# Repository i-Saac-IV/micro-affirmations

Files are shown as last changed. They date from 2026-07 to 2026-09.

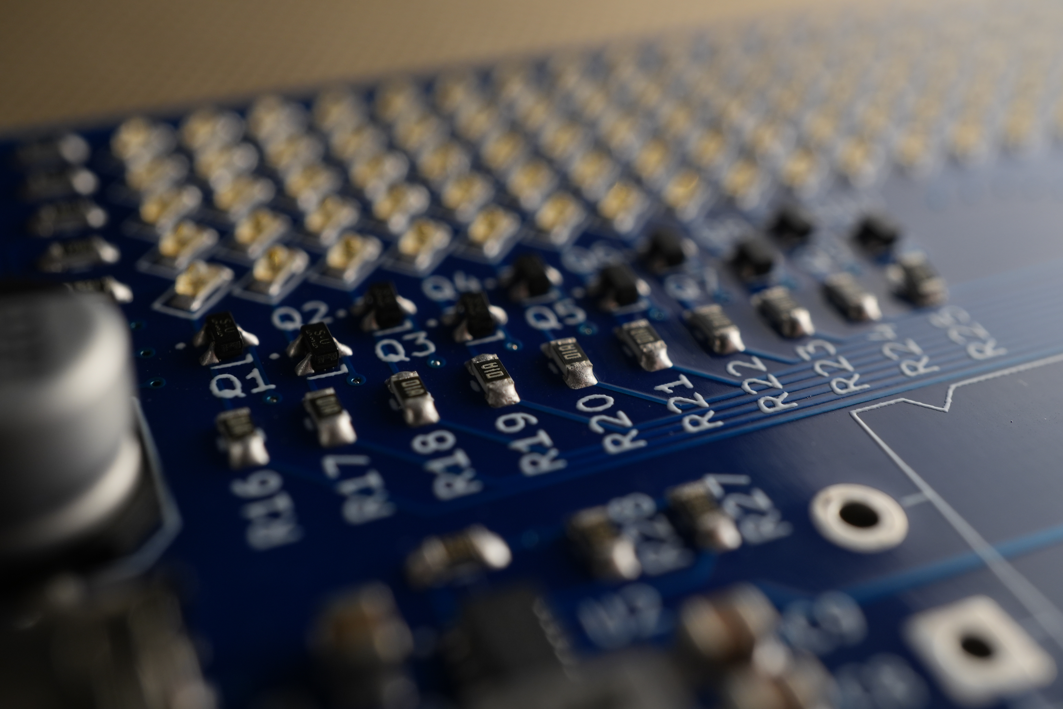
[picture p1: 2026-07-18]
media/DSC01119.JPG

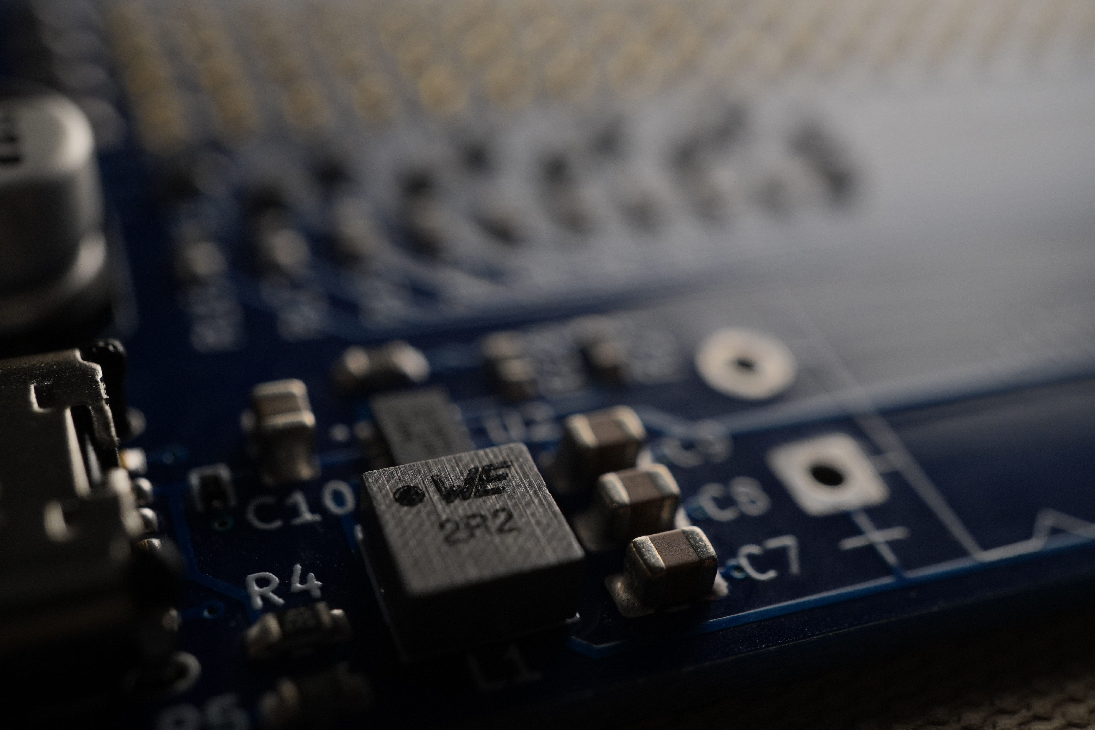
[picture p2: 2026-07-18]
media/DSC01122.JPG

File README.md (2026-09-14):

# µAffirmations
A microcontroller-based affection-giving MACHINE!

> [!IMPORTANT]
> This project is currently a work-in-progress, there __will__ be things that don't work, please bear with me will I work out the kinks!

# Table of Contents
- [Usage Guide](#usage-guide)
  - [Hardware](#hardware)
  - [Firmware](#firmware)
- [Photos](#photos)
- [Project Updates](#project-updates)
- [Copyright and Licensing](#copyright-and-licensing)
- [Contact](#contact)

# Usage Guide
## Hardware
The PCB files can be found [here](/hw/pcb/micro-affirmations.zip), be sure of order a solder stencil too(ideally with a stencil unless you love hand-soldering 200+ SMD connections). The [BOM](/hw/pcb/bom/ibom.html) will provide you with a list of parts required and their placements. Due to the limited size on the PCB, many of the reference designators have been removed to save space. Because of this, you will likely need to have KiCAD or the iBOM running as you are placing components. Or you can guess I suppose...

## Firmware
You will need access to an ST-Link programming device and have [stm32-for-vscode](https://open-vsx.org/extension/bmd/stm32-for-vscode) extension installed. Once you're ready, upload the code by:
- Cloning the repository
- Open in VS code
- Connect the ST-Link programmer to your computer
- Connect the µAffirmations' programming port to the ST-Link programmer
- Ensure the µAffirmations board is powered
- Open the STM32 for VS Code extention
- Click __Flash STM32__

### Message customisation
This device allows the user to create their own custom messages to be displayed on the LED matrix, to provide your messages, modify the following code found in [this](/Core/Src/messages.c) file.

For axample:
```c
__weak const char *messages[] = {
    "This is the first custom message!",
    "Below is a list of supported characters...",
    "!\"#$%&'()*+,-./0123456789:;<=>?@ABCDEFGHIJKLMNOPQRSTUVWXYZ[\\]^_`abcdefghijklmnopqrstuvwxyz{|}~"
};
```

# Photos
<table align="center">
  <tr>
    <td align="center">
      <br>
      <b>Programming port broken in RevB of the PCB</b>
    </td>
  </tr>
</table>

# Project Updates
## Hardware [RevD](https://github.com/i-Saac-IV/micro-affirmations/tree/v0.9.3)
After considerable development to the code, I found out that I had not connected the supercapacitor voltage sensing circuit to a ADC capable pin, this has been corrected. I also found that if the input voltage of the charging IC is greater than the output voltage = 100mV the bucking function of the IC is bypassed (meaning if the input is 5V the output is also 5V, bad for the STM chip), this has been fixed with the linear regulator.

## Hardware [RevC](https://github.com/i-Saac-IV/micro-affirmations/tree/v0.9.2)
After futher testing the following fixes to the hardware design have been made:
- The programming port has been connected to the correct pins on the mircocontroller
- The layout of the components has been adjusted for easier access to the push button
- The supercapacitor management circuit has been de-routed as per the spec sheet
- I added a QR to the PCB, because I could...

## Hardware [RevB](https://github.com/i-Saac-IV/micro-affirmations/tree/v0.9.1)
After hardware tesing the following fixes have been made to the hardware design:
- Supercapacitor charging circuit, now uses a dedecated IC
- LED matrix layout, the LED spacing has been decreased
- LED brightness was assessed and appropriate resistor have been selected
- The overall PCB dimentions have shrunk to 70x40mm
<table align="center">
  <tr>
    <td align="center">
      <br>
      <b>RevB PCB</b>
    </td>
  </tr>
</table>

## Hardware [RevA](https://github.com/i-Saac-IV/micro-affirmations/tree/v0.9.0)
Initial hardware design.

# Copyright and Licensing
See [licence](LICENSE) for in depth info.
<!--
This project uses the following third-party libraries:

- Lib ( License)

Copyright and license terms belong to their respective authors.

Contact me if anything here is incorrect.
-->

# Contact
If you'd like to get in touch, feel free to reach out!
<p>
  <a href="https://github.com/i-Saac-IV">
    
  </a>
  <a href="https://www.linkedin.com/in/isaac-pawley/">
    
  </a>
  <a href="https://www.instagram.com/i.saac.0100/">
    
  </a>
</p>

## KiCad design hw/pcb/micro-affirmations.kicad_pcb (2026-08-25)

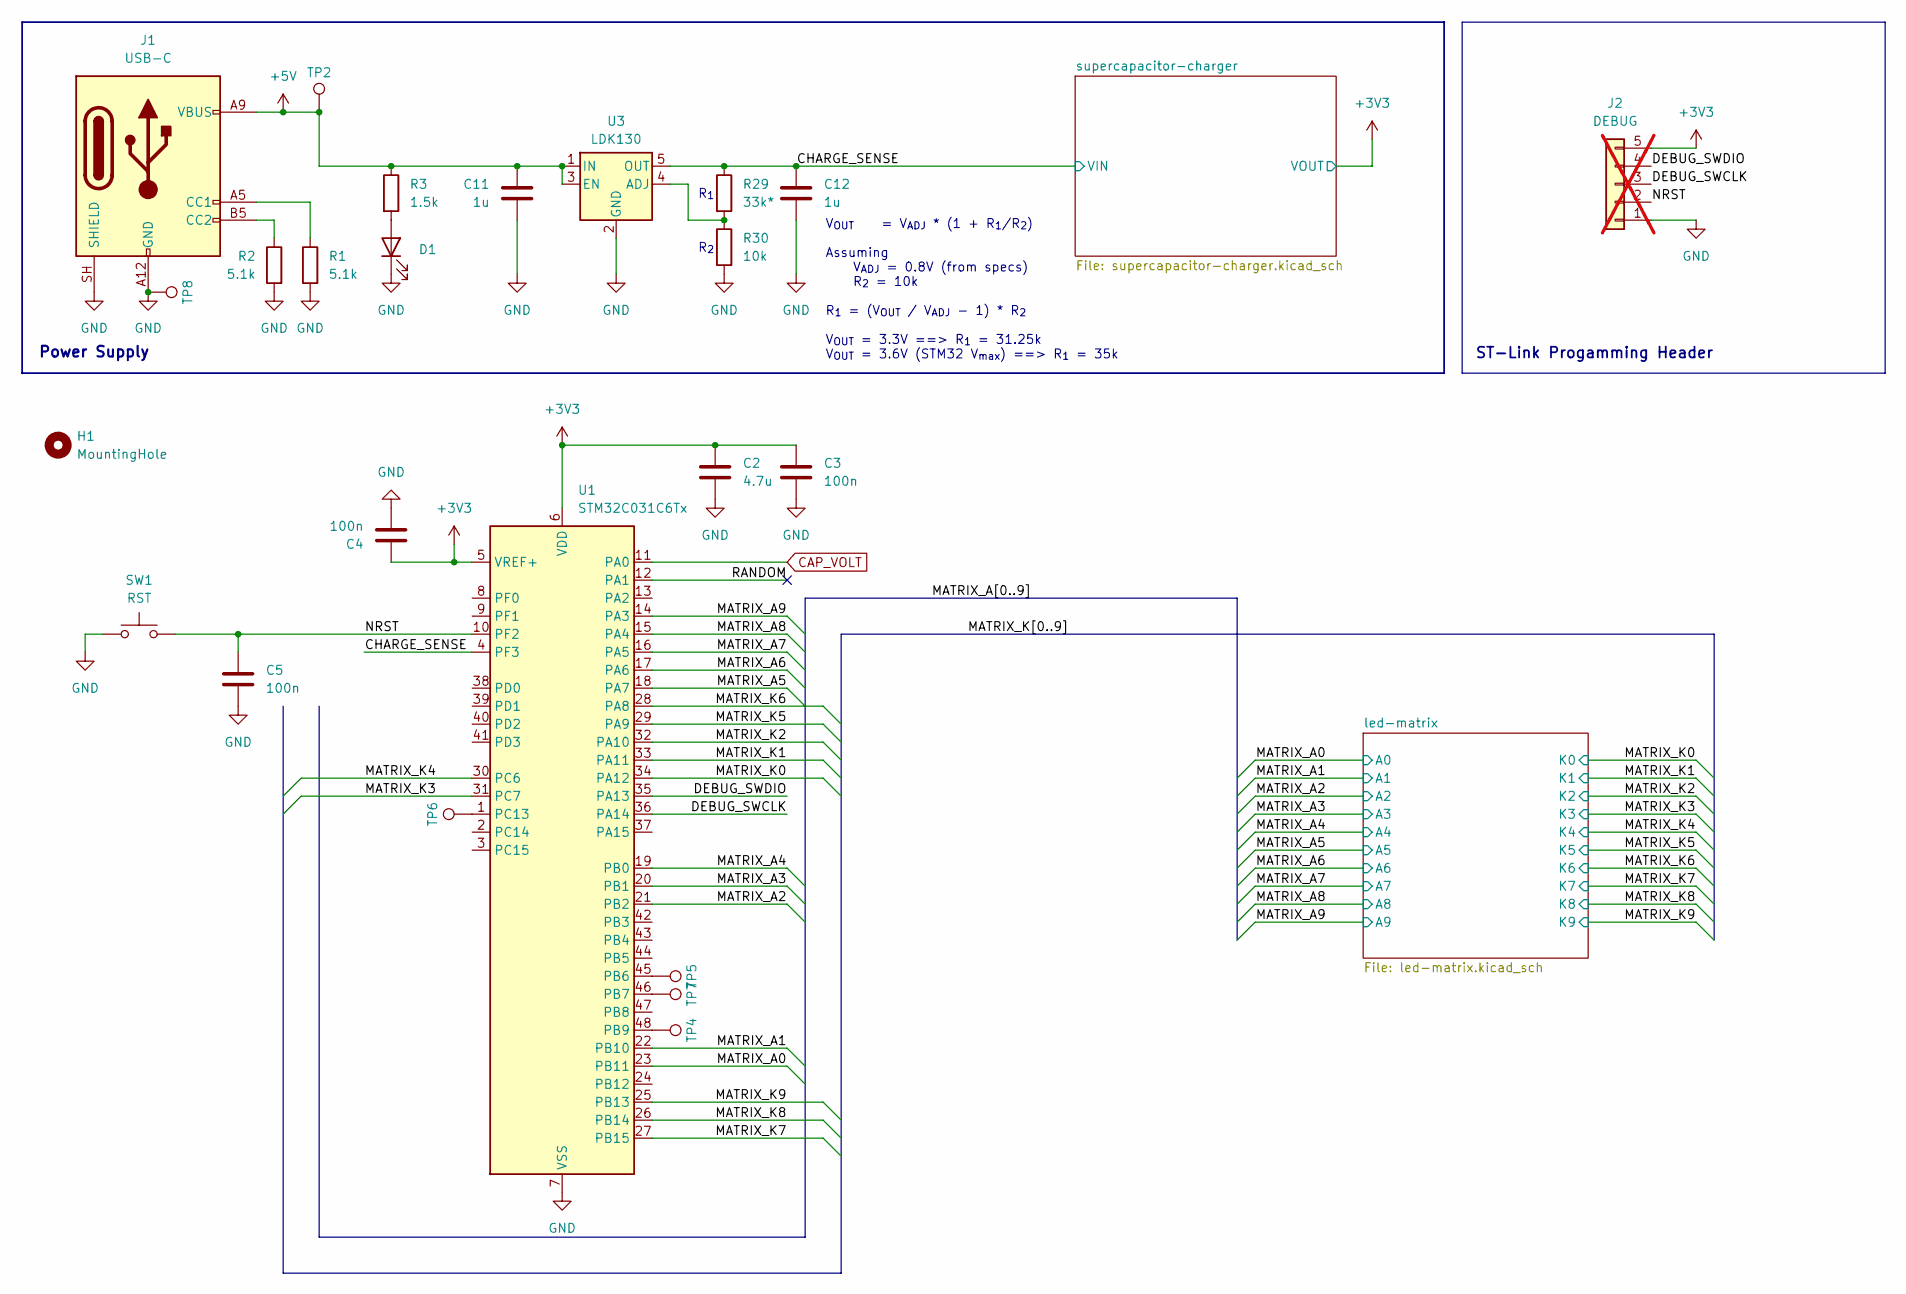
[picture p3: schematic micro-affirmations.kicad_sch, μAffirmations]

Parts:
C2: 4.7u; C_0805_2012Metric
C3, C4, C5: 100n; C_0805_2012Metric
C11, C12: 1u; C_0603_1608Metric
D1: CHARGE; D_0603_1608Metric
H1: MountingHole; MountingHole_2.2mm_M2
J1: USB-C; 2171750001_MOL
J2: DEBUG; PinHeader_1x05_P2.54mm_Vertical; not fitted
R1, R2: 5.1k; R_0603_1608Metric
R3: 1.5k; R_0603_1608Metric
R29: 33k*; R_0603_1608Metric
R30: 10k; R_0603_1608Metric
SW1: RST; TL1030_A
TP2, TP4, TP5, TP6, TP7, TP8: TestPoint; TestPoint_Pad_D1.0mm
U1: STM32C031C6Tx; LQFP-48_7x7mm_P0.5mm
U3: LDK130; SOT-23-5

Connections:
+3V3: C2.1, C3.1, C4.1, J2.5, U1.5 (VREF+), U1.6 (VDD); also elsewhere on the board
+5V: C11.1, J1.A9 (VBUS), J1.B9 (VBUS), R3.1, TP2.1 (1_1), U3.1 (IN), U3.3 (EN)
/CHARGE_SENSE: C12.1, R29.1, U1.4 (PF3), U3.5 (OUT); also elsewhere on the board
/DEBUG_SWCLK: J2.3, U1.36 (PA14)
/DEBUG_SWDIO: J2.4, U1.35 (PA13)
/MATRIX_A0: U1.23 (PB11); also elsewhere on the board
/MATRIX_A1: U1.22 (PB10); also elsewhere on the board
/MATRIX_A2: U1.21 (PB2); also elsewhere on the board
/MATRIX_A3: U1.20 (PB1); also elsewhere on the board
/MATRIX_A4: U1.19 (PB0); also elsewhere on the board
/MATRIX_A5: U1.18 (PA7); also elsewhere on the board
/MATRIX_A6: U1.17 (PA6); also elsewhere on the board
/MATRIX_A7: U1.16 (PA5); also elsewhere on the board
/MATRIX_A8: U1.15 (PA4); also elsewhere on the board
/MATRIX_A9: U1.14 (PA3); also elsewhere on the board
/MATRIX_K0: U1.34 (PA12); also elsewhere on the board
/MATRIX_K1: U1.33 (PA11); also elsewhere on the board
/MATRIX_K2: U1.32 (PA10); also elsewhere on the board
/MATRIX_K3: U1.31 (PC7); also elsewhere on the board
/MATRIX_K4: U1.30 (PC6); also elsewhere on the board
/MATRIX_K5: U1.29 (PA9); also elsewhere on the board
/MATRIX_K6: U1.28 (PA8); also elsewhere on the board
/MATRIX_K7: U1.27 (PB15); also elsewhere on the board
/MATRIX_K8: U1.26 (PB14); also elsewhere on the board
/MATRIX_K9: U1.25 (PB13); also elsewhere on the board
/NRST: C5.1, J2.2, SW1.2, U1.10 (PF2)
/RANDOM: U1.12 (PA1)
CAP_VOLT: U1.11 (PA0); also elsewhere on the board
GND: C2.2, C3.2, C4.2, C5.2, C11.2, C12.2, D1.1 (K), J1.A12 (GND), J1.B12 (GND), J1.SH (SHIELD), J2.1, R1.2, R2.2, R30.2, SW1.1, TP8.1 (1_1), U1.7 (VSS), U3.2 (GND); also elsewhere on the board
unnamed: D1.2 (A), R3.2
unnamed: J1.A5 (CC1), R1.1
unnamed: J1.B5 (CC2), R2.1
unnamed: TP5.1 (1_1), U1.45 (PB6)
unnamed: TP7.1 (1_1), U1.46 (PB7)
unnamed: TP4.1 (1_1), U1.48 (PB9)
unnamed: TP6.1 (1_1), U1.1 (PC13)
unnamed: R29.2, R30.1, U3.4 (ADJ)

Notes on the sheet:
ST-Link Progamming Header
R_{1}
R_{2}
Power Supply
V_{OUT} = V_{ADJ} * (1 + R_{1}/R_{2}) Assuming V_{ADJ} = 0.8V (from specs) R_{2} = 10k R_{1} = (V_{OUT} / V_{ADJ} - 1) * R_{2} V_{OUT} = 3.3V ==> R_{1} = 31.25k V_{OUT} = 3.6V (STM32 V_{max}) ==> R_{1} = 35k

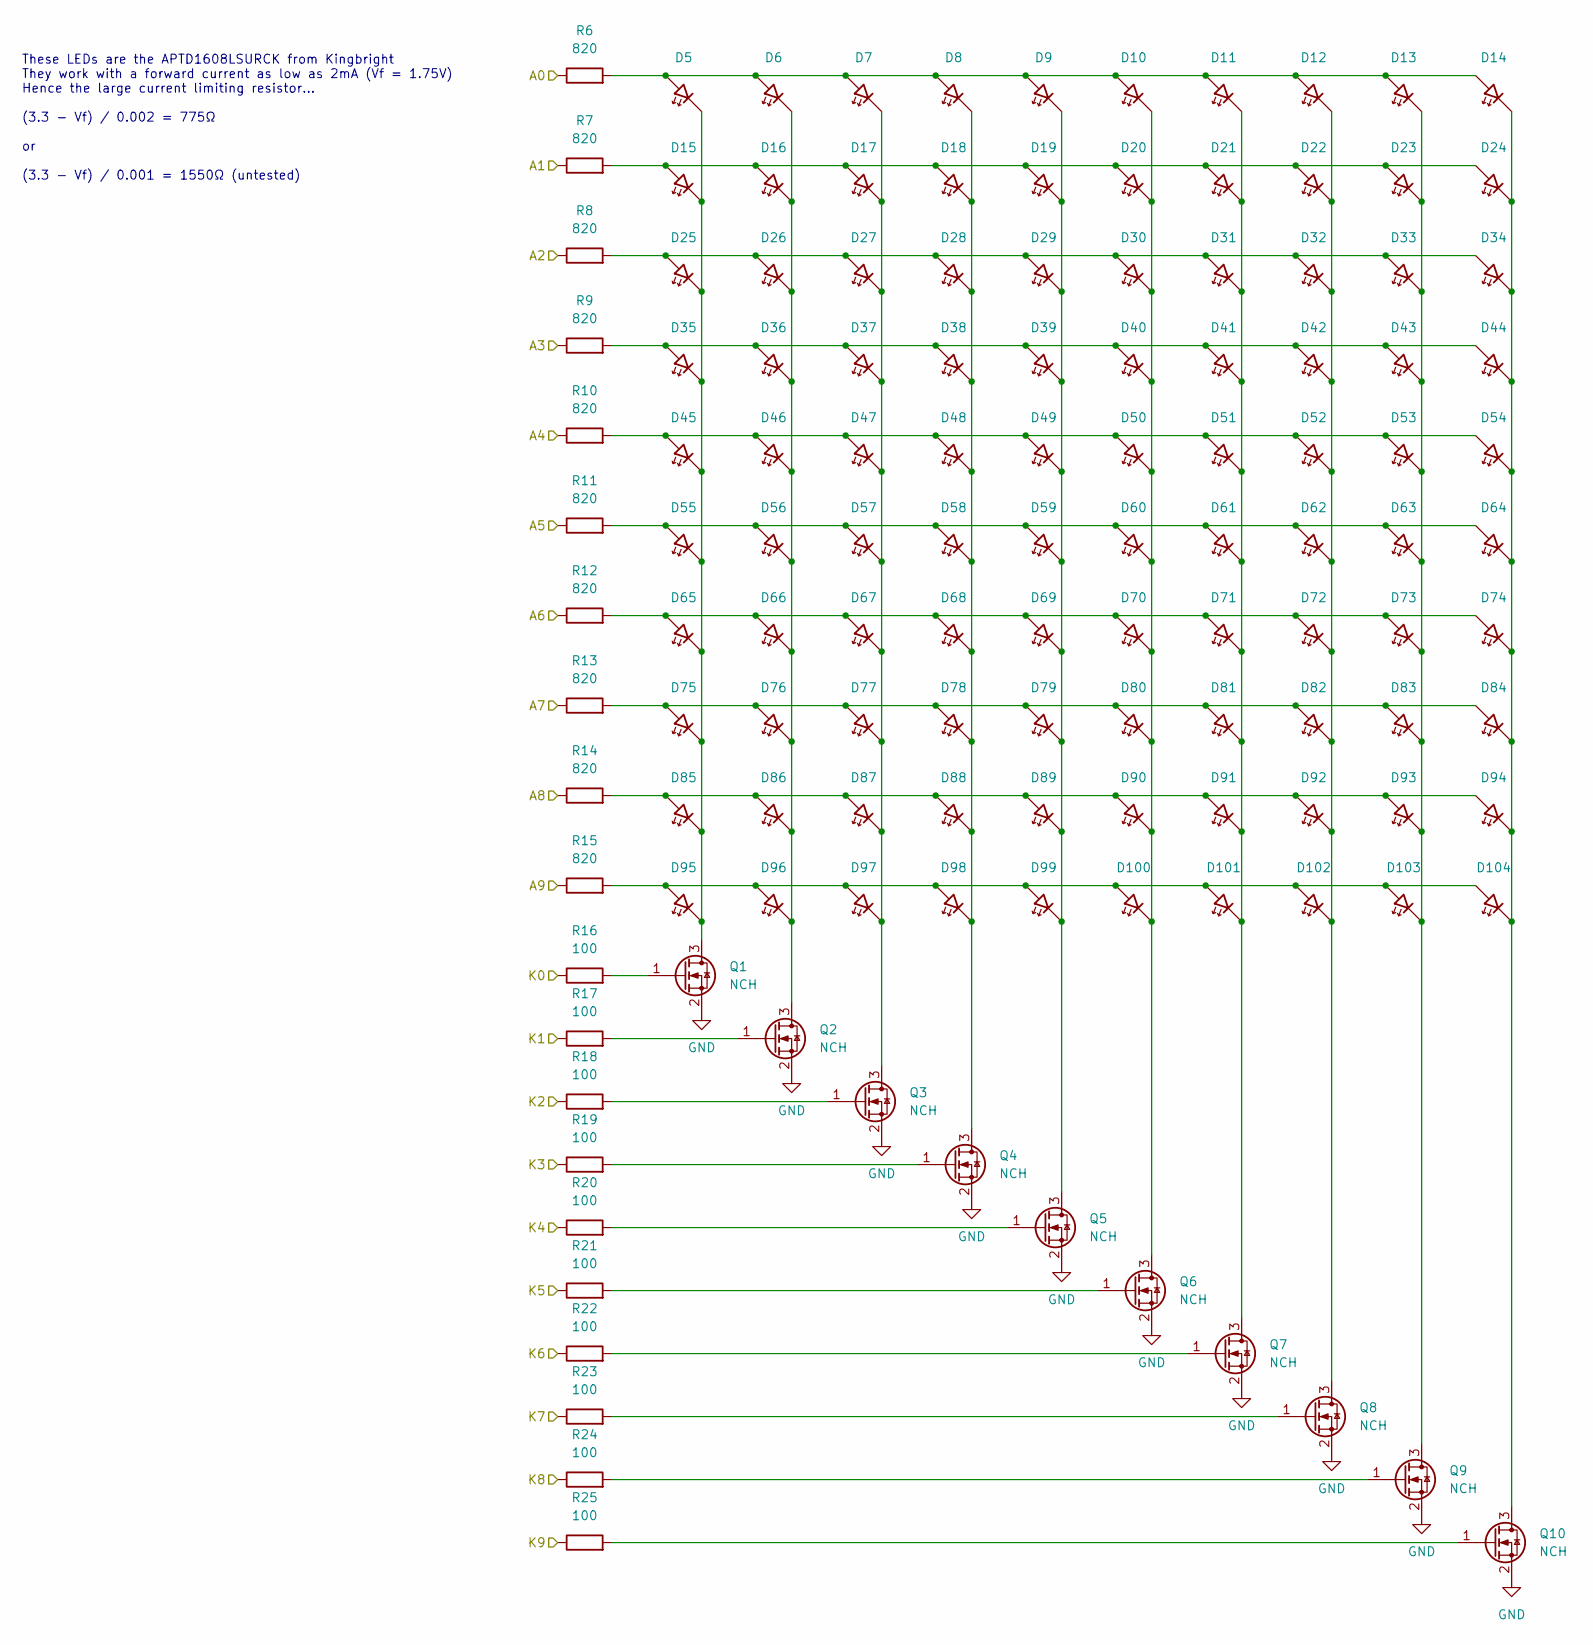
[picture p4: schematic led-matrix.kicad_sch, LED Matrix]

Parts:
D5, D6, D7, D8, D9, D10, D11, D12, D13, D14, D15, D16, D17, D18, D19, D20, D21, D22, D23, D24, D25, D26, D27, D28, D29, D30, D31, D32, D33, D34, D35, D36, D37, D38, D39, D40, D41, D42, D43, D44, D45, D46, D47, D48, D49, D50, D51, D52, D53, D54, D55, D56, D57, D58, D59, D60, D61, D62, D63, D64, D65, D66, D67, D68, D69, D70, D71, D72, D73, D74, D75, D76, D77, D78, D79, D80, D81, D82, D83, D84, D85, D86, D87, D88, D89, D90, D91, D92, D93, D94, D95, D96, D97, D98, D99, D100, D101, D102, D103, D104: LED; D_0603_1608Metric
Q1, Q2, Q3, Q4, Q5, Q6, Q7, Q8, Q9, Q10: NCH; SOT-416
R6, R7, R8, R9, R10, R11, R12, R13, R14, R15: 820; R_0603_1608Metric
R16, R17, R18, R19, R20, R21, R22, R23, R24, R25: 100; R_0603_1608Metric

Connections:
/MATRIX_A0: R6.1; also elsewhere on the board
/MATRIX_A1: R7.1; also elsewhere on the board
/MATRIX_A2: R8.1; also elsewhere on the board
/MATRIX_A3: R9.1; also elsewhere on the board
/MATRIX_A4: R10.1; also elsewhere on the board
/MATRIX_A5: R11.1; also elsewhere on the board
/MATRIX_A6: R12.1; also elsewhere on the board
/MATRIX_A7: R13.1; also elsewhere on the board
/MATRIX_A8: R14.1; also elsewhere on the board
/MATRIX_A9: R15.1; also elsewhere on the board
/MATRIX_K0: R16.1; also elsewhere on the board
/MATRIX_K1: R17.1; also elsewhere on the board
/MATRIX_K2: R18.1; also elsewhere on the board
/MATRIX_K3: R19.1; also elsewhere on the board
/MATRIX_K4: R20.1; also elsewhere on the board
/MATRIX_K5: R21.1; also elsewhere on the board
/MATRIX_K6: R22.1; also elsewhere on the board
/MATRIX_K7: R23.1; also elsewhere on the board
/MATRIX_K8: R24.1; also elsewhere on the board
/MATRIX_K9: R25.1; also elsewhere on the board
GND: Q1.2 (S), Q2.2 (S), Q3.2 (S), Q4.2 (S), Q5.2 (S), Q6.2 (S), Q7.2 (S), Q8.2 (S), Q9.2 (S), Q10.2 (S); also elsewhere on the board
unnamed: D5.2 (A), D6.2 (A), D7.2 (A), D8.2 (A), D9.2 (A), D10.2 (A), D11.2 (A), D12.2 (A), D13.2 (A), D14.2 (A), R6.2
unnamed: D10.1 (K), D20.1 (K), D30.1 (K), D40.1 (K), D50.1 (K), D60.1 (K), D70.1 (K), D80.1 (K), D90.1 (K), D100.1 (K), Q6.3 (D)
unnamed: D15.2 (A), D16.2 (A), D17.2 (A), D18.2 (A), D19.2 (A), D20.2 (A), D21.2 (A), D22.2 (A), D23.2 (A), D24.2 (A), R7.2
unnamed: D5.1 (K), D15.1 (K), D25.1 (K), D35.1 (K), D45.1 (K), D55.1 (K), D65.1 (K), D75.1 (K), D85.1 (K), D95.1 (K), Q1.3 (D)
unnamed: D6.1 (K), D16.1 (K), D26.1 (K), D36.1 (K), D46.1 (K), D56.1 (K), D66.1 (K), D76.1 (K), D86.1 (K), D96.1 (K), Q2.3 (D)
unnamed: D7.1 (K), D17.1 (K), D27.1 (K), D37.1 (K), D47.1 (K), D57.1 (K), D67.1 (K), D77.1 (K), D87.1 (K), D97.1 (K), Q3.3 (D)
unnamed: D8.1 (K), D18.1 (K), D28.1 (K), D38.1 (K), D48.1 (K), D58.1 (K), D68.1 (K), D78.1 (K), D88.1 (K), D98.1 (K), Q4.3 (D)
unnamed: D9.1 (K), D19.1 (K), D29.1 (K), D39.1 (K), D49.1 (K), D59.1 (K), D69.1 (K), D79.1 (K), D89.1 (K), D99.1 (K), Q5.3 (D)
unnamed: D25.2 (A), D26.2 (A), D27.2 (A), D28.2 (A), D29.2 (A), D30.2 (A), D31.2 (A), D32.2 (A), D33.2 (A), D34.2 (A), R8.2
unnamed: D35.2 (A), D36.2 (A), D37.2 (A), D38.2 (A), D39.2 (A), D40.2 (A), D41.2 (A), D42.2 (A), D43.2 (A), D44.2 (A), R9.2
unnamed: D45.2 (A), D46.2 (A), D47.2 (A), D48.2 (A), D49.2 (A), D50.2 (A), D51.2 (A), D52.2 (A), D53.2 (A), D54.2 (A), R10.2
unnamed: D55.2 (A), D56.2 (A), D57.2 (A), D58.2 (A), D59.2 (A), D60.2 (A), D61.2 (A), D62.2 (A), D63.2 (A), D64.2 (A), R11.2
unnamed: D65.2 (A), D66.2 (A), D67.2 (A), D68.2 (A), D69.2 (A), D70.2 (A), D71.2 (A), D72.2 (A), D73.2 (A), D74.2 (A), R12.2
unnamed: D75.2 (A), D76.2 (A), D77.2 (A), D78.2 (A), D79.2 (A), D80.2 (A), D81.2 (A), D82.2 (A), D83.2 (A), D84.2 (A), R13.2
unnamed: D85.2 (A), D86.2 (A), D87.2 (A), D88.2 (A), D89.2 (A), D90.2 (A), D91.2 (A), D92.2 (A), D93.2 (A), D94.2 (A), R14.2
unnamed: D95.2 (A), D96.2 (A), D97.2 (A), D98.2 (A), D99.2 (A), D100.2 (A), D101.2 (A), D102.2 (A), D103.2 (A), D104.2 (A), R15.2
unnamed: D11.1 (K), D21.1 (K), D31.1 (K), D41.1 (K), D51.1 (K), D61.1 (K), D71.1 (K), D81.1 (K), D91.1 (K), D101.1 (K), Q7.3 (D)
unnamed: D12.1 (K), D22.1 (K), D32.1 (K), D42.1 (K), D52.1 (K), D62.1 (K), D72.1 (K), D82.1 (K), D92.1 (K), D102.1 (K), Q8.3 (D)
unnamed: D13.1 (K), D23.1 (K), D33.1 (K), D43.1 (K), D53.1 (K), D63.1 (K), D73.1 (K), D83.1 (K), D93.1 (K), D103.1 (K), Q9.3 (D)
unnamed: D14.1 (K), D24.1 (K), D34.1 (K), D44.1 (K), D54.1 (K), D64.1 (K), D74.1 (K), D84.1 (K), D94.1 (K), D104.1 (K), Q10.3 (D)
unnamed: Q1.1 (G), R16.2
unnamed: Q2.1 (G), R17.2
unnamed: Q3.1 (G), R18.2
unnamed: Q4.1 (G), R19.2
unnamed: Q5.1 (G), R20.2
unnamed: Q6.1 (G), R21.2
unnamed: Q7.1 (G), R22.2
unnamed: Q8.1 (G), R23.2
unnamed: Q9.1 (G), R24.2
unnamed: Q10.1 (G), R25.2

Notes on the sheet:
These LEDs are the APTD1608LSURCK from Kingbright They work with a forward current as low as 2mA (Vf = 1.75V) Hence the large current limiting resistor... (3.3 - Vf) / 0.002 = 775Ω or (3.3 - Vf) / 0.001 = 1550Ω (untested)

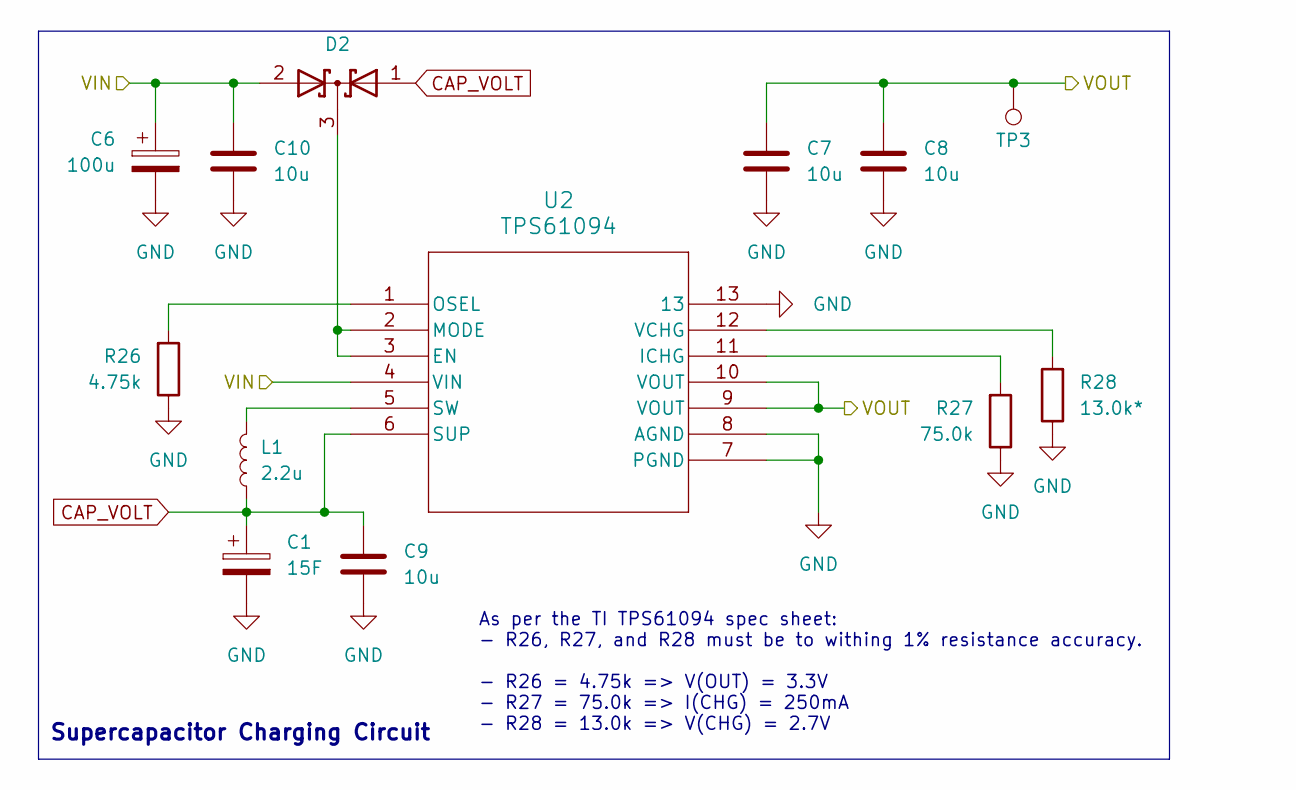
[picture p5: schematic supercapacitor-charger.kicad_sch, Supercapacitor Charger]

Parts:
C1: 15F; CP_Radial_L32.0mm_D12.5mm_P5.00mm_Horizontal
C6: 100u; CP_Elec_6.3x5.4_Nichicon
C7, C8, C9, C10: 10u; C_0805_2012Metric
D2: SOT-23
L1: 2.2u; L_1616_4040Metric
R26: 4.75k; R_0603_1608Metric
R27: 75.0k; R_0603_1608Metric
R28: 13.0k*; R_0603_1608Metric
TP3: TestPoint; TestPoint_Pad_D1.0mm
U2: TPS61094; WSON_94DSSR_TEX

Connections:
+3V3: C7.1, C8.1, TP3.1 (1_1), U2.9 (VOUT), U2.10 (VOUT); also elsewhere on the board
/CHARGE_SENSE: C6.1, C10.1, D2.2 (A), U2.4 (VIN); also elsewhere on the board
CAP_VOLT: C1.1, C9.1, D2.1 (A), L1.2, U2.6 (SUP); also elsewhere on the board
GND: C1.2, C6.2, C7.2, C8.2, C9.2, C10.2, R26.1, R27.1, R28.1, U2.7 (PGND), U2.8 (AGND), U2.13; also elsewhere on the board
unnamed: D2.3 (K), U2.2 (MODE), U2.3 (EN)
unnamed: R27.2, U2.11 (ICHG)
unnamed: R26.2, U2.1 (OSEL)
unnamed: L1.1, U2.5 (SW)
unnamed: R28.2, U2.12 (VCHG)

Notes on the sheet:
As per the TI TPS61094 spec sheet: - R26, R27, and R28 must be to withing 1% resistance accuracy. - R26 = 4.75k => V(OUT) = 3.3V - R27 = 75.0k => I(CHG) = 250mA - R28 = 13.0k => V(CHG) = 2.7V
Supercapacitor Charging Circuit

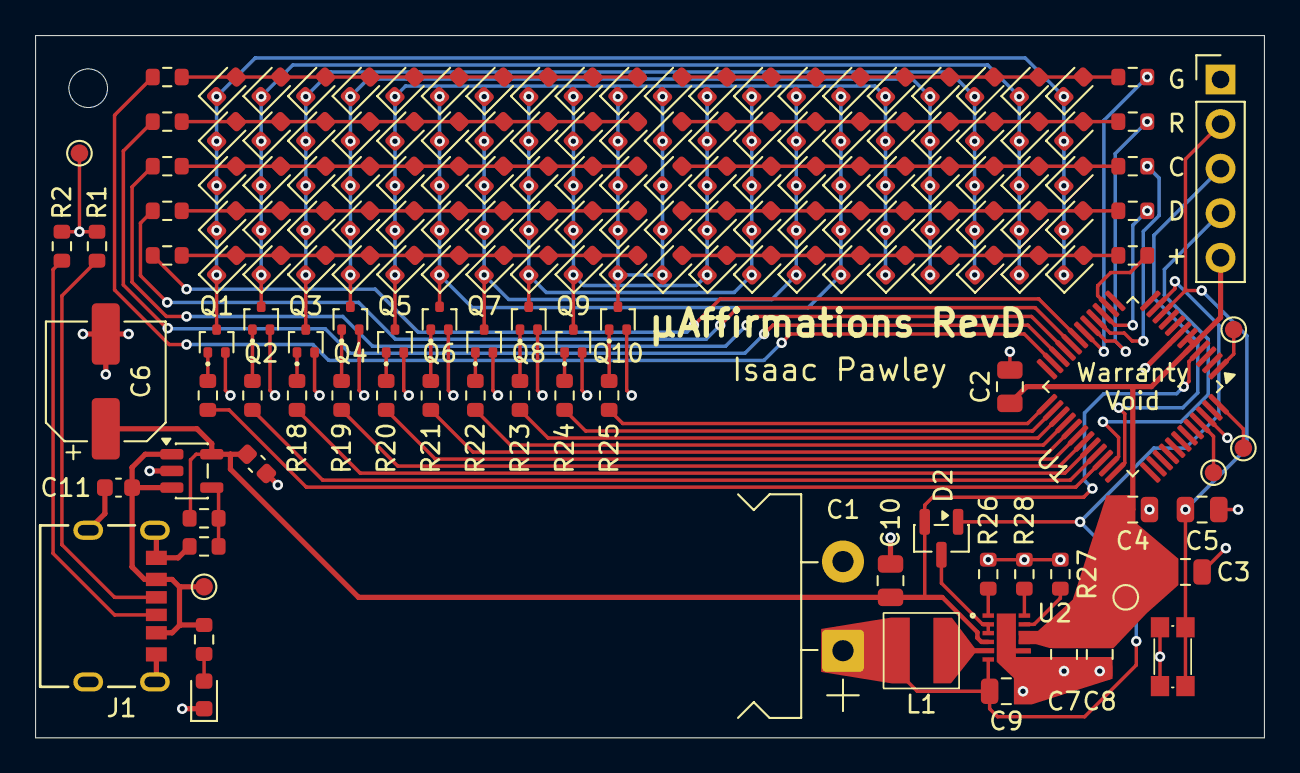
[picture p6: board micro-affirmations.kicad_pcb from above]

Board: 2 copper layers, 70.0 x 40.0 mm, 167 parts (1 on the bottom side), 71 nets.

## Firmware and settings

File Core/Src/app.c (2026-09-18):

/*

File:   app.h
Author: Isaac Pawley

*/

#include "app.h"

#include "adc.h"
#include "stm32c0xx_hal.h"

#define DEBUG_ENABLED 0

void enter_shutdown(void) {
    __HAL_RCC_PWR_CLK_ENABLE();
    __HAL_PWR_CLEAR_FLAG(PWR_FLAG_WUF);
    
    HAL_PWREx_EnterSHUTDOWNMode();
}

#include "nanoGL.h"
#include "matrix.h"
#include "messages.h"
#include "bitmaps.h"
#include "adc_handler.h"
#include "capacitor.h"

void app_updateMultiplex(void) {
    matrix_updateMultiplex();
}

void app_main(void) {
    nanoGL_clear();
    adc_handler_start();

    while (!adc_handler_isReady()) {
        // wait...
    }

    size_t message_index = adc_handler_getValue(ADC_RANDOM) % number_of_messages;

    uint32_t next_update_ms = 0;

    static int16_t scrollX = PHYSICAL_COLS;

    while (HAL_GPIO_ReadPin(CHARGE_SENSE_GPIO_Port, CHARGE_SENSE_Pin)) {
        if (HAL_GetTick() >= next_update_ms) {
            next_update_ms = HAL_GetTick() + 100;
            adc_handler_start();
            capacitor_update();
        }
    }

    while (1) {
        if (HAL_GetTick() > next_update_ms) {
            next_update_ms = HAL_GetTick() + 50;
            nanoGL_clear();

            nanoGL_drawString(scrollX, 0, messages[message_index], &Font_5x5);
            scrollX--;
            
            if (scrollX < -nanoGL_stringWidth(messages[message_index], &Font_5x5)) {
                if (DEBUG_ENABLED) {
                    message_index = adc_handler_getValue(ADC_RANDOM) % number_of_messages;
                    scrollX = PHYSICAL_COLS;
                } else {
                    adc_handler_start();
                    capacitor_update();

                    HAL_Delay(1500);

                    enter_shutdown();
                }               
            }
        }
    }    
}

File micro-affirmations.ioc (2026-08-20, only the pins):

Mcu.UserName=STM32C031C6Tx
PA0.GPIO_Label=CAP_VOLT
PA0.Signal=ADC1_IN0
PA1.GPIO_Label=RANDOM
PA1.Signal=ADC1_IN1
PA10.GPIO_Label=MATRIX_K2
PA10.Signal=GPIO_Output
PA13.Signal=DEBUG_SWDIO
PA14-BOOT0.Signal=DEBUG_SWCLK
PA3.GPIO_Label=MATRIX_A9
PA3.Signal=GPIO_Output
PA4.GPIO_Label=MATRIX_A8
PA4.Signal=GPIO_Output
PA5.GPIO_Label=MATRIX_A7
PA5.Signal=GPIO_Output
PA6.GPIO_Label=MATRIX_A6
PA6.Signal=GPIO_Output
PA7.GPIO_Label=MATRIX_A5
PA7.Signal=GPIO_Output
PA8.GPIO_Label=MATRIX_K6
PA8.Signal=GPIO_Output
PA9.GPIO_Label=MATRIX_K5
PA9.Signal=GPIO_Output
PB0.GPIO_Label=MATRIX_A4
PB0.Signal=GPIO_Output
PB1.GPIO_Label=MATRIX_A3
PB1.Signal=GPIO_Output
PB10.GPIO_Label=MATRIX_A1
PB10.Signal=GPIO_Output
PB11.GPIO_Label=MATRIX_A0
PB11.Signal=GPIO_Output
PB13.GPIO_Label=MATRIX_K9
PB13.Signal=GPIO_Output
PB14.GPIO_Label=MATRIX_K8
PB14.Signal=GPIO_Output
PB15.GPIO_Label=MATRIX_K7
PB15.Signal=GPIO_Output
PB2.GPIO_Label=MATRIX_A2
PB2.Signal=GPIO_Output
PC6.GPIO_Label=MATRIX_K4
PC6.Signal=GPIO_Output
PC7.GPIO_Label=MATRIX_K3
PC7.Signal=GPIO_Output
PF3.GPIO_Label=CHARGE_SENSE
PF3.Signal=GPIO_Input

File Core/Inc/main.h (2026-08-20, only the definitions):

#define CHARGE_SENSE_Pin GPIO_PIN_3
#define CHARGE_SENSE_GPIO_Port GPIOF
#define CAP_VOLT_Pin GPIO_PIN_0
#define CAP_VOLT_GPIO_Port GPIOA
#define RANDOM_Pin GPIO_PIN_1
#define RANDOM_GPIO_Port GPIOA
#define MATRIX_A9_Pin GPIO_PIN_3
#define MATRIX_A9_GPIO_Port GPIOA
#define MATRIX_A8_Pin GPIO_PIN_4
#define MATRIX_A8_GPIO_Port GPIOA
#define MATRIX_A7_Pin GPIO_PIN_5
#define MATRIX_A7_GPIO_Port GPIOA
#define MATRIX_A6_Pin GPIO_PIN_6
#define MATRIX_A6_GPIO_Port GPIOA
#define MATRIX_A5_Pin GPIO_PIN_7
#define MATRIX_A5_GPIO_Port GPIOA
#define MATRIX_A4_Pin GPIO_PIN_0
#define MATRIX_A4_GPIO_Port GPIOB
#define MATRIX_A3_Pin GPIO_PIN_1
#define MATRIX_A3_GPIO_Port GPIOB
#define MATRIX_A2_Pin GPIO_PIN_2
#define MATRIX_A2_GPIO_Port GPIOB
#define MATRIX_A1_Pin GPIO_PIN_10
#define MATRIX_A1_GPIO_Port GPIOB
#define MATRIX_A0_Pin GPIO_PIN_11
#define MATRIX_A0_GPIO_Port GPIOB
#define MATRIX_K9_Pin GPIO_PIN_13
#define MATRIX_K9_GPIO_Port GPIOB
#define MATRIX_K8_Pin GPIO_PIN_14
#define MATRIX_K8_GPIO_Port GPIOB
#define MATRIX_K7_Pin GPIO_PIN_15
#define MATRIX_K7_GPIO_Port GPIOB
#define MATRIX_K6_Pin GPIO_PIN_8
#define MATRIX_K6_GPIO_Port GPIOA
#define MATRIX_K5_Pin GPIO_PIN_9
#define MATRIX_K5_GPIO_Port GPIOA
#define MATRIX_K4_Pin GPIO_PIN_6
#define MATRIX_K4_GPIO_Port GPIOC
#define MATRIX_K3_Pin GPIO_PIN_7
#define MATRIX_K3_GPIO_Port GPIOC
#define MATRIX_K2_Pin GPIO_PIN_10
#define MATRIX_K2_GPIO_Port GPIOA
#define MATRIX_K1_Pin GPIO_PIN_11
#define MATRIX_K1_GPIO_Port GPIOA
#define MATRIX_K0_Pin GPIO_PIN_12
#define MATRIX_K0_GPIO_Port GPIOA

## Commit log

2026-04-08 chore: updated gitignore for kicad, mxcube and vscode
2026-04-08 chore: added initial kicad files
    [micro-affirmations.kicad_pcb, micro-affirmations.kicad_sch]
2026-04-08 chore: added initial stm32 files
2026-04-11 feat: added usb-c footprint
2026-04-11 feat: added supercapacitor footprint
2026-04-11 feat: added button footprint
2026-04-11 chore: added symbol and footprint libraries
2026-04-11 feat: completed initail hardware design
    [led-matrix.kicad_sch, micro-affirmations.kicad_pcb, micro-affirmations.kicad_sch]
2026-04-13 fix: added programming and debug port to schematic
    [led-matrix.kicad_sch, micro-affirmations.kicad_pcb, micro-affirmations.kicad_sch]
2026-04-13 chore: component footprint layout complete
    [micro-affirmations.kicad_pcb]
2026-04-14 fix: updated programming and debug port to include nrst
    [micro-affirmations.kicad_sch]
2026-04-14 feat: completed pcb layout for revision a
    [micro-affirmations.kicad_pcb, micro-affirmations.kicad_sch]
2026-04-14 feat: added gerbers of revision a
2026-04-14 chore: updated gitignore to exclude raw gerber files
2026-05-11 chore: added inductor footprint
2026-05-11 chore: added charger ic symbol
2026-05-11 feat: added improved circuit for charging supercapacitor
    [supercapacitor-charger.kicad_sch]
2026-05-11 feat: revision b pcb generated
2026-05-11 docs: added revision b bom
    [micro-affirmations_RevB_BOM.csv]
2026-05-11 fix: changed bom name
    [micro-affirmations_BOM.csv]
2026-07-09 chore: removed bom
    [micro-affirmations_BOM.csv]
2026-07-09 chore: removed gerber files
2026-07-09 feat: revision c pcb generated
2026-07-09 fix: corrected mosfet footprint
    [led-matrix.kicad_sch]
2026-07-09 chore: added revision c bom
    [micro-affirmations_RevC_BOM.csv]
2026-07-09 chore: updated pin functions to match schematic
2026-07-13 feat: printing aces to screen
2026-07-17 chore: generated code to use timer to trigger display refresh
2026-07-17 fix: mutiplexing is now updated using a timer and interupt
    [app.c]
2026-07-17 chore: now using pin labels
2026-07-17 chore: added bitmap drawing and started on capacitor voltage detection - relised there's a hardware fault
2026-07-17 chore: added bitmaps when charging
2026-07-17 fix: swapped capacitor voltage pins
    [micro-affirmations.kicad_sch]
2026-07-17 chore: exported hardware revision d files
    [micro-affirmations.kicad_pcb]
2026-08-19 fix: updated matrix code for revision c pcb
    [matrix.c]
2026-08-19 fix: updated schematics to pcb revision d
    [led-matrix.kicad_sch, micro-affirmations.kicad_pcb, micro-affirmations.kicad_sch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]
2026-08-19 chore: updated bom to revision d
    [micro-affirmations_BOM.csv, micro-affirmations_RevC_BOM.csv]
2026-08-19 docs: minor update to readme about revision d of pcb
2026-08-19 fix: update debug flag
    [app.c]
2026-08-20 chore: updated mxcube to use new cap volt pin
2026-08-20 feat: capacitor charging animation working
2026-08-20 chore: setup dma for adc
2026-08-20 fix: analog pins now use the adc via the dma
    [app.c, capacitor.c]
2026-08-20 fix: removed fake shutdown
    [app.c]
2026-08-21 fix: added schottky diode or gate to enable pin
    [supercapacitor-charger.kicad_sch]
2026-08-21 fix: added or-ing diode to board
    [micro-affirmations.kicad_pcb, supercapacitor-charger.kicad_sch]
2026-08-25 chore: added stars to potentially different components
    [micro-affirmations.kicad_sch, supercapacitor-charger.kicad_sch]
2026-08-25 chore: finalised pcb for rev d export
    [micro-affirmations.kicad_pcb]
2026-08-25 chore: export revision d gerbers
    [micro-affirmations_BOM.csv]
2026-09-14 chore: removed old bom, updated readme
    [micro-affirmations_BOM.csv]
2026-09-14 fix: dma giving new adc values
    [app.c]
2026-09-18 fix: sped up the capacitor updates
    [app.c]

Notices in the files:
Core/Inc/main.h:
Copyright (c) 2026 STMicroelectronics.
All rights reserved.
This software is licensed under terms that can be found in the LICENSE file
